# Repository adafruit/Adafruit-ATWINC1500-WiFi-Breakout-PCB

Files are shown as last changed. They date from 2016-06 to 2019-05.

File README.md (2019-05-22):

## Adafruit ATWINC1500 WiFi Breakout PCB
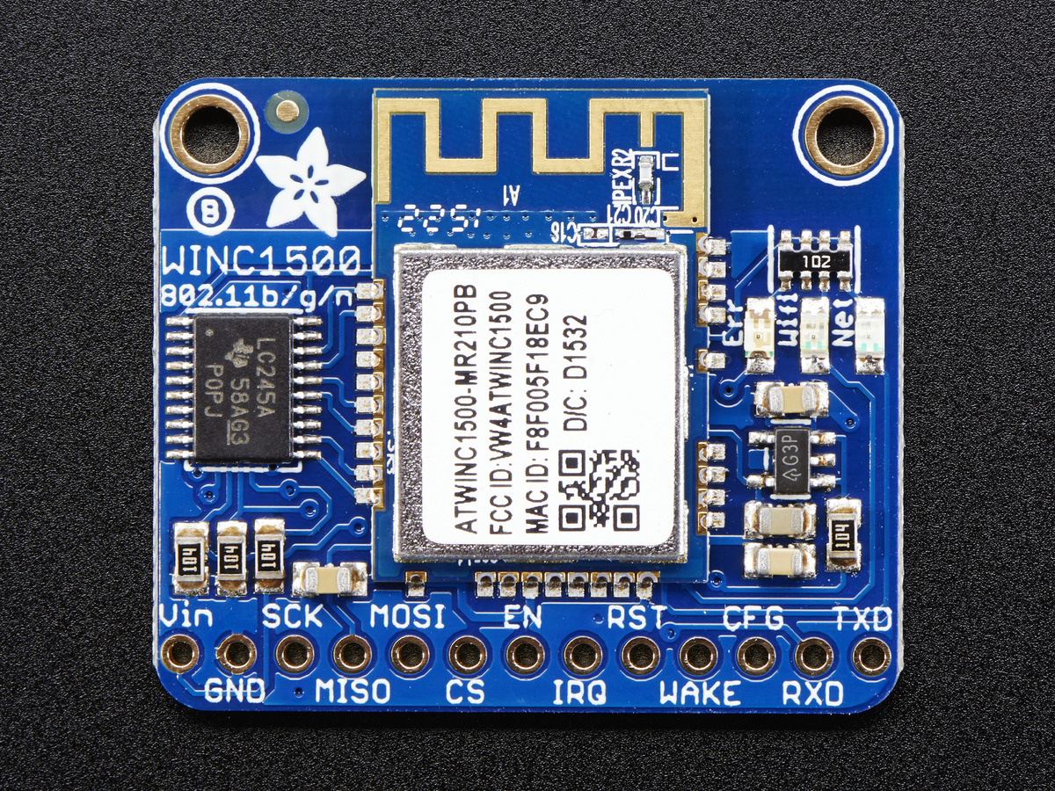
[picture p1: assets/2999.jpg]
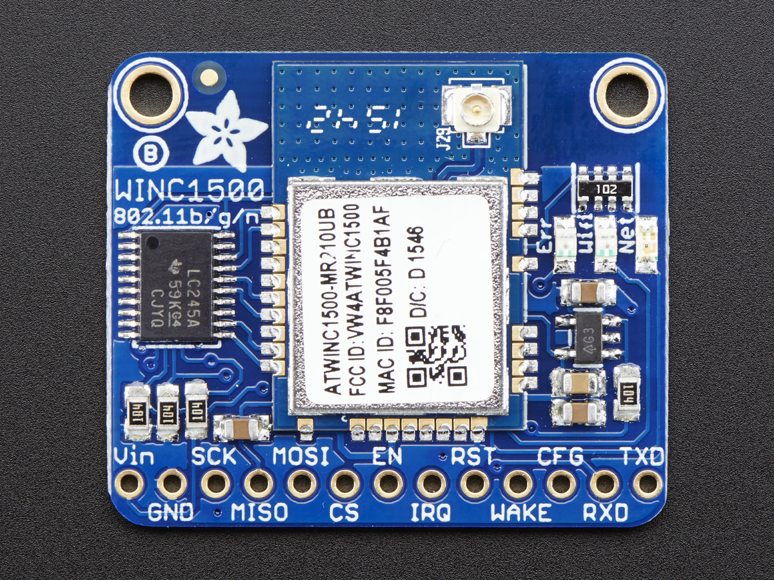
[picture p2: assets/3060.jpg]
&nbsp; <br />
Click to purchase from the Adafruit Shop:
- [Adafruit ATWINC1500 WiFi Breakout](https://www.adafruit.com/product/2999)
- [Adafruit ATWINC1500 WiFi Breakout with uFL Connector - fw 19.4.4](https://www.adafruit.com/product/3060)

These 802.11bgn-capable WiFi modules are the best new thing for networking your devices, with SSL support and rock solid performance - running our adafruit.io MQTT demo for a full weekend straight with no hiccups (it would have run longer but we had to go to work, so we unplugged it). We like these so much, they've completely replaced the CC3000 module on all our projects.

The Adafruit ATWINC1500 WiFi Breakouts use SPI to communicate, so with about 6 wires, you can get your wired up and ready to go. And scanning/connecting to networks is very fast, a few seconds.

These modules work with 802.11b, g, or n networks & supports WEP, WPA and WPA2 encryption. You can use them in Soft AP mode to create an ad-hoc network. For secure client connections, there is TLS 1.2 support in firmware 19.4.4!

PCB files for the Adafruit ATWINC1500 WiFi Breakout. The format is EagleCAD schematic and board layout

For more details, check out the product pages at

   * https://www.adafruit.com/product/2999
   * https://www.adafruit.com/product/3060

### License

Adafruit invests time and resources providing this open source design, please support Adafruit and open-source hardware by [purchasing products from Adafruit](https://www.adafruit.com)!

All text above must be included in any redistribution

Designed by Limor Fried/Ladyada for Adafruit Industries.
Creative Commons Attribution/Share-Alike, all text above must be included in any redistribution. 
See license.txt for additional information.

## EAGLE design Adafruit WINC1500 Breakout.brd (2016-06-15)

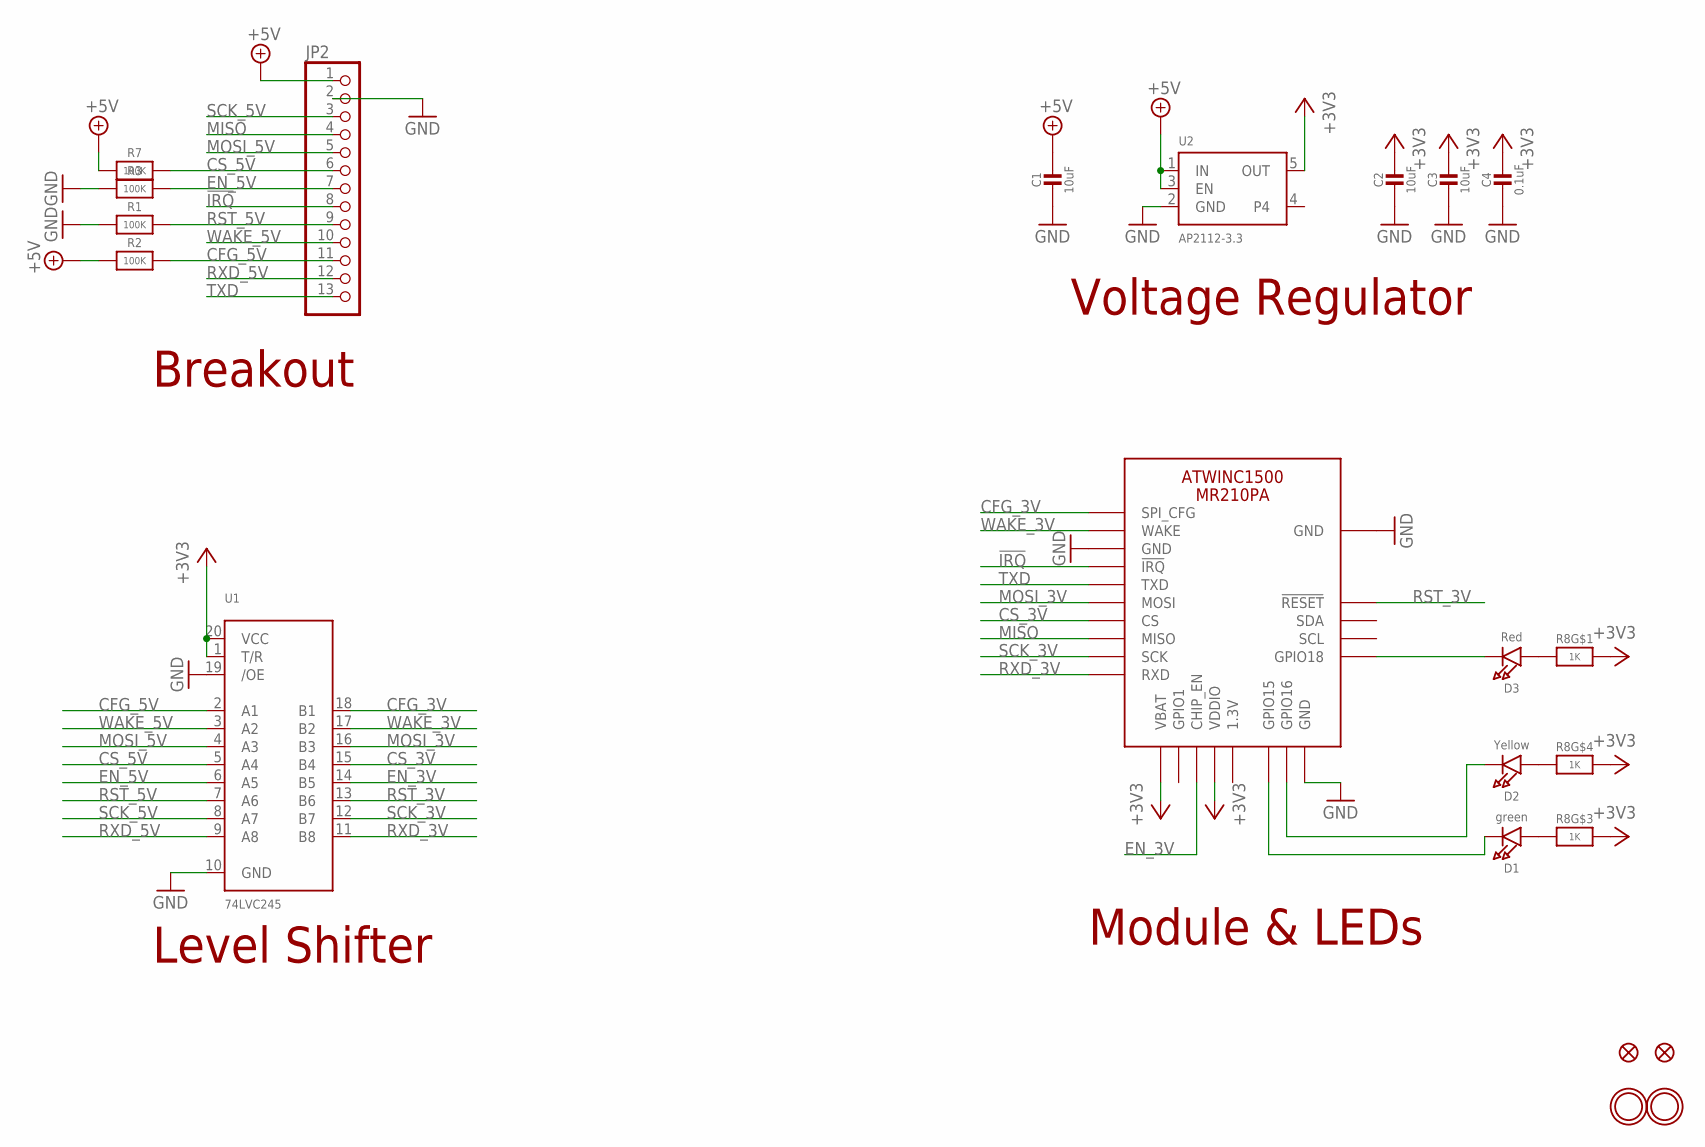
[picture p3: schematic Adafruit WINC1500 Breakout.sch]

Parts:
C1, C3: 10uF; 0805-NO
C2: 10uF; 0805_10MGAP
C4: 0.1uF; 0805-NO
D1: green; CHIPLED_0805_NOOUTLINE
D2: Yellow; CHIPLED_0805_NOOUTLINE
D3: Red; CHIPLED_0805_NOOUTLINE
FID1, FID2: FIDUCIAL""; FIDUCIAL_1MM
JP2: HEADER-1X13; 1X13_ROUND_70
R1, R2: 100K; 0805-NO
R3, R7: 100K; _0805MP
R8: 1K; RESPACK_4X0603
U1: 74LVC245; TSSOP20
U2: AP2112-3.3; SOT23-5
U$1: ATWINC1500_MR210PB; ATWINC1500_MR210PA
U$2, U$3: MOUNTINGHOLE2.5; MOUNTINGHOLE_2.5_PLATED

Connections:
!IRQ: JP2.8, U$1.J13 (!IRQ)
+3V3: C2.1, C3.1, C4.1, R8.5 (2), R8.6 (2), R8.8 (2), U1.1 (T/R), U1.20 (VCC), U2.5 (OUT), U$1.J20 (VBAT), U$1.J23 (VDDIO)
+5V: C1.1, JP2.1, R2.1, R7.1, U2.1 (IN), U2.3 (EN)
CFG_3V: U1.18 (B1), U$1.J10 (SPI_CFG)
CFG_5V: JP2.11, R2.2, U1.2 (A1)
CS_3V: U1.15 (B4), U$1.J16 (CS)
CS_5V: JP2.6, R7.2, U1.5 (A4)
EN_3V: U1.14 (B5), U$1.J22 (CHIP_EN)
EN_5V: JP2.7, R3.2, U1.6 (A5)
GND: C1.2, C2.2, C3.2, C4.2, JP2.2, R1.1, R3.1, U1.10 (GND), U1.19 (/OE), U2.2 (GND), U$1.J9 (GND), U$1.J12 (GND), U$1.J28 (GND), U$1.MTGND (GND)
GPIO15: D1.C, U$1.J26 (GPIO15)
GPIO16: D2.C, U$1.J27 (GPIO16)
GPIO18: D3.C, U$1.J1 (GPIO18)
MISO: JP2.4, U$1.J17 (MISO)
MOSI_3V: U1.16 (B3), U$1.J15 (MOSI)
MOSI_5V: JP2.5, U1.4 (A3)
unnamed: D3.A, R8.1
unnamed: D2.A, R8.4 (1)
unnamed: D1.A, R8.3 (1)
RST_3V: U1.13 (B6), U$1.J4 (!RESET)
RST_5V: JP2.9, R1.2, U1.7 (A6)
RXD_3V: U1.11 (B8), U$1.J19 (RXD)
RXD_5V: JP2.12, U1.9 (A8)
SCK_3V: U1.12 (B7), U$1.J18 (SCK)
SCK_5V: JP2.3, U1.8 (A7)
TXD: JP2.13, U$1.J14 (TXD)
WAKE_3V: U1.17 (B2), U$1.J11 (WAKE)
WAKE_5V: JP2.10, U1.3 (A2)

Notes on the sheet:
Voltage Regulator
Breakout
Level Shifter
Module & LEDs

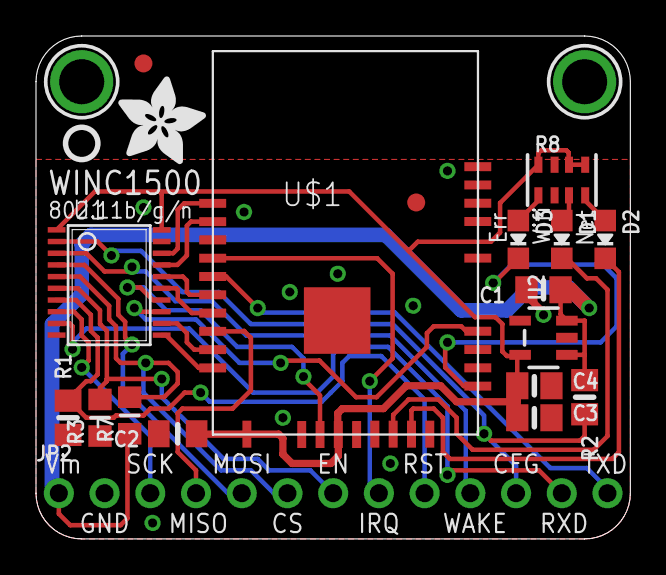
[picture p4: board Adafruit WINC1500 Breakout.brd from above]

Board: 2 copper layers, 33.0 x 27.9 mm, 23 parts (1 on the bottom side), 28 nets.

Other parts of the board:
U$4: ADAFRUIT_5MM
U$5: PCBFEAT-REV-040
U$6: ADAFRUIT_TEXT_20MM

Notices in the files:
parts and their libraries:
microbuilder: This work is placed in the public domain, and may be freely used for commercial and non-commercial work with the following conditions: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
